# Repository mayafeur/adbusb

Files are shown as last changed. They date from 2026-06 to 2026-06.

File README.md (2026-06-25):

**Arduino software to share an ADB keyboard between an ADB computer (old Macintosh and Apple IIgs) and a USB computer.**

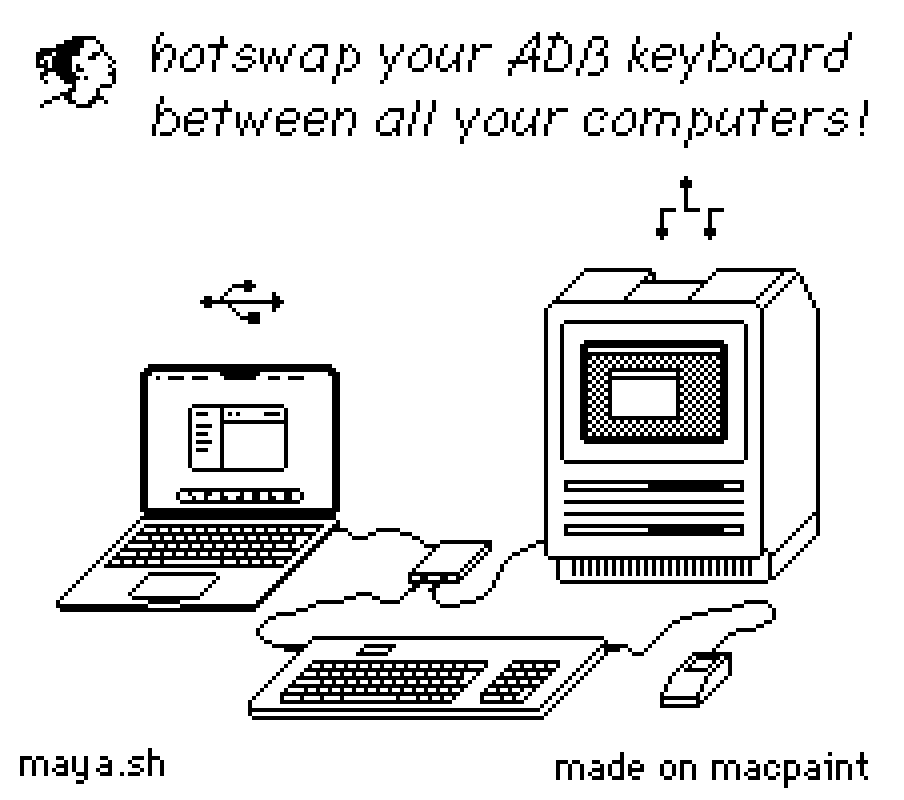
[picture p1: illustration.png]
pixelart illustration showing a macintosh se and a macbook sharing an adb keyboard


## What works

- adb passthrough between a macintosh and a keyboard
  - handle other devices on the bus (like a mouse)
  - relay softpower signal (macintosh ii, quadra, powermac...)
  - no electric connection between data lines or softpower lines
- adb keyboard to usb-hid conversion:
  - iso and ansi layouts
  - locking caps lock
  - power key in usb (translated as 0x66 "keyboard power")
- auto switch when a computer is off
- tested on multiple keyboards: aek ii, m0116/m0118, appledesign
- tested on macintosh se and powermac g3

## What don't work yet

- keyboard leds on usb: the *keyboard.h* library doesn't handle hid output reports
- hotplugging adb: works randomly, the microcontroller don't like that
- mouse passthrough in usb mode
- keyboard detection at startup by the macintosh if arduino in usb mode: still usable tho
- collision detection handling: the program calls the keyboard at address 2

## Hardware needed

- arduino pro micro because it works on 5V and is hid capable
- 2 mini-din 4 pin connectors (only one if using only adb-to-usb)
- a resistor (1K) for the pull up
- a button (optional if using only adb-to-usb)
- a diode (optional, to power the arduino from adb)

## How to build it

- connect button between 2 and GND
- connect 9 to the mini-din A pin 1 (computer adb data)
- connect 8 to the mini-din A pin 2 (computer adb softpower)
- connect mini-din A pin 3 to RAW through the diode (pass from mini-DIN to RAW)
- connect 10 to the mini-din B pin 1 (keyboard adb data) then to VCC through resistor
- connect 16 to the mini-din B pin 2 (keyboard adb softpower)
- connect RAW to the mini-din B pin 3 (keyboard 5V power)
- connect GND on the two mini-din pins 4
- mark din A as the macintosh connector and din B as the keyboard connector (put a sticker or whatever)

Mini-DIN female connector front view :
```
/------\
| 4  3 |
| 2  1 |
\__==__/
```

Arduino Pro Micro pinout :
```
                                ___________ 
                     PD3  TXD  |    USB    |  RAW        --- keyboard pin 3 ---
                     PD2   20  |           |  GND        --- keyboard pin 4    |
computer pin 4 ---        GND  |           |  RST                              |
  button pin 1 ---        GND  |           |  VCC                              |
  button pin 2 ---   PD1    2  |           |  A3   PF4                         |
                     PD0    3  |           |  A2   PF5                         _
                     PD4    4  |           |  A1   PF6                        | |
                     PC6    5  |           |  A0   PF7            1K resistor | |
                     PD7    6  |           |  15   PB1                        |_|
                     PE6    7  |           |  14   PB3                         |
computer pin 2 ---   PB4    8  |           |  16   PB2   --- keyboard pin 2    |
computer pin 1 ---   PB5    9  |___________|  10   PB6   --- keyboard pin 1 ---
computer pin 3 --->| RAW
```

## How to compile and upload it

1. install `arduino-cli`
2. `arduino-cli core install arduino:avr`
3. `arduino-cli lib install Keyboard`
4. compile this project by `cd` in then `arduino-cli compile --fqbn arduino:avr:micro`
5. connect the board to the computer
6. get board port with `arduino-cli board list`
7. upload it `arduino-cli upload -p /dev/.......`

## References

- [Guide to the Macintosh family hardware, Chapter 8 : Apple Desktop Bus, Apple, 1990](https://archive.org/details/apple-guide-macintosh-family-hardware/page/n325/mode/2up)
- [Apple Desktop Bus Protocol, lopaciuk.eu, 2021](https://www.lopaciuk.eu/2021/03/26/apple-adb-protocol.html)
- [Understanding the ADB Service Request Signal, bigmessowires, 2016](https://www.bigmessowires.com/2016/03/30/understanding-the-adb-service-request-signal/)
- [Apple Desktop Bus (ADB), wiki.preterhuman.net](https://wiki.preterhuman.net/Apple_Desktop_Bus_(ADB))

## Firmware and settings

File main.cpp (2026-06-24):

#include <Arduino.h>
#include "gpio.h"
#include "main.h"
#include "adb.h"
#include "map.h"
#include "hid.h"

void passthrough_mode() {
    uint8_t command_byte;
    int i;
    while(true) {
        if(is_button_changed_state() || !is_high(HOST_DATA)) {
            blink_kb();
            break;
        }
        if(!is_high(KB_SOFTPOWER)) {
            press_host_softpower();
        }
        TCNT1 = 0;
        while(is_high(HOST_DATA) && TCNT1 <= 75 * 2);
        bool is_listen = (command_byte & 0b00001100) == 0b00001000;
        bool command_complete = !is_listen || i < -2;
        if(TCNT1 >= 75 * 2 && command_complete) {
            int kb_high_timeout = 185;  // max stop-to-start 260 - 75 us
            while(true) {
                TCNT1 = 0;
                while(is_high(KB_DATA) && TCNT1 < kb_high_timeout * 2);
                if(TCNT1 >= kb_high_timeout * 2) {
                    break;
                }
                kb_high_timeout = 75;
                set_low(HOST_DATA);
                while(!is_high(KB_DATA));
                set_release(HOST_DATA);
            }
        }
        while(is_high(HOST_DATA));
        set_low(KB_DATA);
        TCNT1 = 0;
        while(!is_high(HOST_DATA) && TCNT1 < 20000);  // 10 ms timeout for button
        set_release(KB_DATA);
        int low_time = TCNT1 / 2;
        if(low_time > 700) {  // attention low
            i = 7;  // 8 bits command
            command_byte = 0;
        }
        else {
            bool bit = low_time < 50 ? 1 : 0;
            if(i >= 0) {  // if command_byte not complete 
                command_byte |= (bit << i);
            }
            i--;
            if(i == -2 && !is_high(KB_DATA)) {  // if first stop bit + keyboard SRQ
                set_low(HOST_DATA);
                while(!is_high(KB_DATA));
                set_release(HOST_DATA);
            }
        }
    }
}

void translation_mode() {
	while(true) {
        if(is_button_changed_state() || (USBDevice.isSuspended() && is_high(HOST_DATA))) {
            blink_kb();
            break;
        }
		key_event_t ev = transaction_get_keys();
		translate_key_press(ev.keycode_1, ev.pressed_1);
		translate_key_press(ev.keycode_2, ev.pressed_2);
        delay(11);  // like an original adb host
	}
    transaction_flush_mouse();
}

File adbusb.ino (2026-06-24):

#include "adb.h"
#include "gpio.h"
#include "hid.h"
#include "main.h"

void setup() {
	// timer for adb timings
	TCCR1A = 0;
    TCCR1B = 0b00000010; // prescaler 8 (2 MHz)
	
	// pull-up for button
	pinMode(SWITCH_BUTTON, INPUT_PULLUP);

	hid_init();
    reset();  // needed only for M0116/M0118
}

void loop() {
	translation_mode();
	passthrough_mode();
}

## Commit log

2026-06-24 breaking changes
    refactoring
    button at different pin
    different button handling
2026-06-24 detection for unplugged device
